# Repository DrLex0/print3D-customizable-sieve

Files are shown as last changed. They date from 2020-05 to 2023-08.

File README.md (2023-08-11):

# Customizable sieve / filter / strainer
*3D printable parametric sieve / filter / strainer (formerly thing:2578935)*

### License
[Creative Commons - Attribution](https://creativecommons.org/licenses/by/4.0/)

### Attribution
Based on Sieve (or ‘Seive’) by pcstru ([Thingiverse thing:341357](https://www.thingiverse.com/thing:341357)).

### Gallery

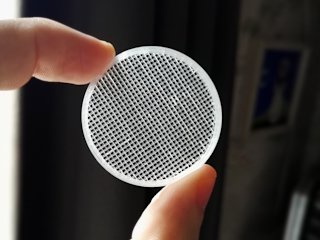
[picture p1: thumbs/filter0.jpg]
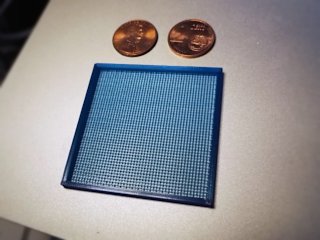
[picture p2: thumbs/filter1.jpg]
Comparison
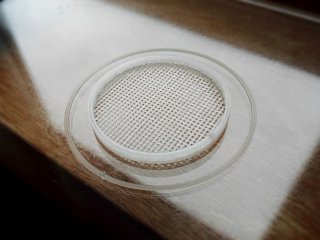
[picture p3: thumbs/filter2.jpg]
[🔎](images/filter0.jpg) [🔎](images/filter1.jpg) [🔎](images/filter2.jpg)

## Description and Instructions

This is an enhanced and customizable version of the [sieve by pcstru](https://www.thingiverse.com/thing:341357). It allows to make sieves, filters, strainers, or whatever you like to call them, in various shapes and dimensions.

Open the `.scad` file in [OpenSCAD](https://www.openscad.org/) and **[use the OpenSCAD Customizer](https://www.dr-lex.be/3d-printing/customizer.html)** to create a model with your own desired specifications.

Compared to pcstru's original, this updated version has these extra features:
* choose between round, square, or heart shapes;
* option to make any regular polygon shape by reducing the number of circle segments. The polygon will fit inside a circle of the specified outer diameter (this means making a 4-sided polygon is not the same as selecting the ‘square’ shape);
* ability to make a rectangular or elliptical shape with the `stretch` value to extend the shape in one direction (not applicable to heart shape);
* optionally add a taper to create funnel-like filters (not applicable to heart shape);
* there is a bit of extra overlap between the walls and grid, such that the grid should be well-attached to the rim even when using few or thin strands;
* the grid is perfectly centered at all times, courtesy of my unstoppable urge for detail. (But, the origin can be adjusted if desired.)

You can opt to print the grid as one set of layers, i.e. a plane with holes in it, or to print two sets of strands on top of each other (‘offset’ option). The latter is easier and probably faster to print, and may yield a more accurate filter if hole size is important. The disadvantage is that dirt tends to stick to the filter more easily.

You can also opt to lift the grid. This allows to print accurate filters with strands merely as wide as your nozzle diameter (see photos). Set the lift distance to your *first layer height* to ensure the filter only starts being printed at the *second* layer. This avoids that the strands get squished against the bed, or printed with a wider first layer extrusion, both of which would make the hole size inaccurate. You could also use a raft to the same effect, but it might be difficult to remove the filter form the raft without damaging it.

The segments parameter also affects the heart shape, but you should use a multiple of 4 in this case to ensure a smooth and usable shape.

### Print settings

The examples in the photos were printed at 0.2 mm layers, but any layer height should work. Infill should usually be set to 100% unless you are printing a design with very wide walls or so.

Both prints shown in the photos use 0.4 mm strands (with offset), and were lifted 0.25 mm (first layer height) off the bed.

For filters with narrow strands, you should ensure the extrusion width matches the strand width.

If you are trying to print a filter with a fine mesh that is only 1 extrusion wide, and the mesh disappears entirely when slicing, ensure that slicer options similar to “detect thin walls” are enabled.

## Updates

### 2017/10/10: v2.0

First published to Thingiverse.

### 2020/02/26: v2.1

Added limits and steps to parameters, to make this more usable in the OpenSCAD customizer.
Also allowed to make the outer ring shorter than the grid, or omit it entirely (use a height of 0).

### 2020/05/15: migrated to GitHub.

### 2022/03/23: v2.2

Added ‘stretch’ parameter to allow creating elongated shapes (rectangles, ellipses). Refactored the code to be more straightforward.

### 2022/05/19: v2.3

Added ‘taper’ parameter (thanks to beettlle) to generate funnel-like shapes.

### 2023/05/21: v2.4

Added grid rotation and heart shape (thanks to rixvet).

### 2023/08/11: v2.5

Allow shifting the position of the grid; reduce rendering time of final mesh by generating less structures that will be trimmed anyhow.

## Tags
`customizable`, `filter`, `grid`, `mesh`, `openscad`, `sieve`, `strainer`

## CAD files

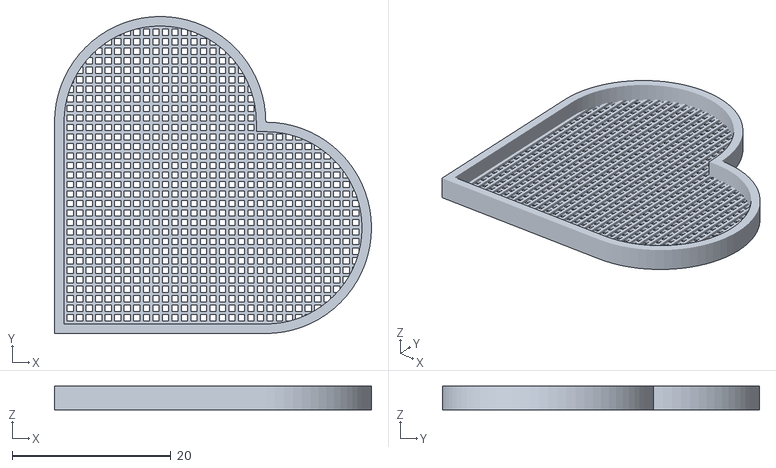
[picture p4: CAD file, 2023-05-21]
examples/sieve-heart-40mm-s_4-g_8.stl
40.0 x 40.0 x 3.00

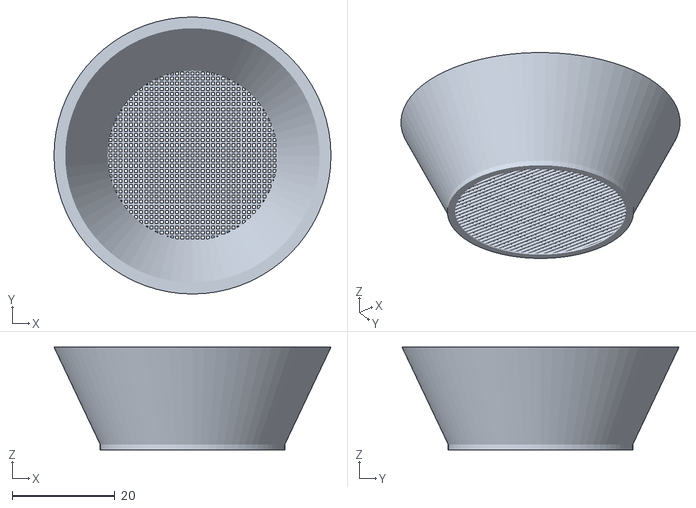
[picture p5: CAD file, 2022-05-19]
examples/sieve-funnel-36to54mm-s_4-g_6.stl
54.0 x 54.0 x 20.0

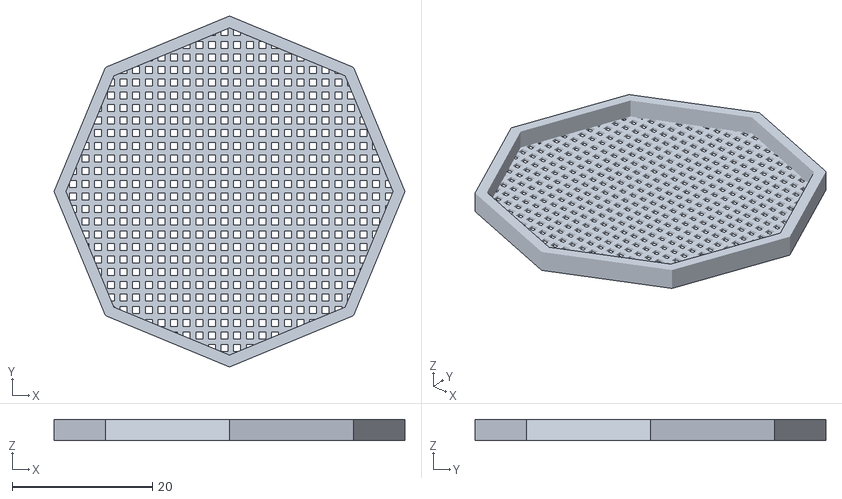
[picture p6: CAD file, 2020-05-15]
examples/sieve-poly8-50mm-s_8-g1.stl
50.0 x 50.0 x 3.00

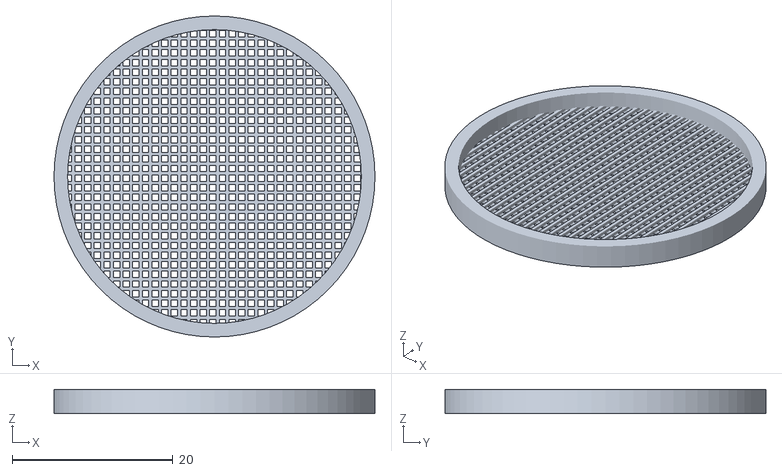
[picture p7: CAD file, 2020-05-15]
examples/sieve-round-40mm-s_4-g_8.stl
40.0 x 40.0 x 3.00

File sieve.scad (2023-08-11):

/* Customizable sieve by DrLex and contributors, formerly thing:2578935
 * based on Sieve (or Seive?) by pcstru (thing:341357).
 * Released under Creative Commons - Attribution - Share Alike license
 * https://github.com/DrLex0/print3D-customizable-sieve
 * Version 2.5, 2023/08
 */

shape = "round"; // [round,square,heart]

// All dimensions are in millimeters. For square shape, this is the length of one side. For heart shape, this is the width and depth of the heart.
outer_diameter = 40; //[5.0:.1:250.0]

// Additional X dimension length for creating elongated shapes (rectangles or ellipses). Not applicable to heart shape.
stretch = 0.0; //[0:.1:250.0]

// Width of the filter wires. You shouldn't try to go below your nozzle diameter, although it might work within certain limits.
strand_width = .4; //[.10:.01:10.00]

// Thickness (height) of the filter wires. If 'Offset strands' is enabled, the filter grid will be twice this thick.
strand_thickness = .4; //[.10:.01:5]

// Spacing between filter wires, i.e. hole size.
gap_size = .8; //[.10:.01:10.00]

// Rotation (in degrees) of filter wires in relation to shape.
grid_rotation = 0; // [0:1:90]

// Thickness (width) of the outer rim (will increase with height if taper > 1).
rim_thickness = 1.7; //[.3:.01:5]

// Total height of the outer rim.
rim_height = 3; //[0:.1:50]

// Taper of the tube: scale factor of top versus bottom contour. Not applicable to heart shape.
taper = 1; //[1:0.01:3]

// If yes, the wires will be placed in different layers, which leads to a quicker and possibly better print, especially when using thin strands.
offset_strands = "yes"; // [yes,no]

// For most accurate results with thin strands, set this to your first layer height. This will ensure the strands only start printing from the second layer, avoiding any problems due to the first layer being squished, or using a wider extrusion, etc.
lift_strands = 0; //[0.00:.01:2.00]

// Shift origin of the grid, percentage of grid pattern size (100% shift is same as 0% shift)
shift_x = 0; //[0:1:99]
shift_y = 0; //[0:1:99]

// Number of segments for round shape, low values can be used to obtain polygons that fit inside a circle of the specified outer diameter. For instance, 3 yields a triangle. Also affects heart shape.
$fn = 72; //[3:1:256]


/* [Hidden] */
shift_x_abs = (gap_size + strand_width) * shift_x / 100;
shift_y_abs = (gap_size + strand_width) * shift_y / 100;


module flat_heart(r_x, r_y, thick, inside) {
    // radius + 2 * square
    s_x = (r_x * 2) / 1.5;
    b = s_x / 2;
    w = thick * 2;

    if (inside == 1) {
    translate([-r_x, -r_x ,0])
    union() {
            square(s_x);
            translate([b, s_x, 0]) circle(d=s_x);
            translate([s_x, b, 0]) circle(d=s_x);
        }
    } else {
        translate([-r_x, -r_x ,0])
        difference() {
            union() {
                square(s_x);
                translate([b, s_x, 0]) circle(d=s_x);
                translate([s_x, b, 0]) circle(d=s_x);

            }
            translate([w/2, w/2]) square([s_x-(w/2), s_x-w]);
            translate([w/2, w/2]) square([s_x-w, s_x-(w/2)]);
            translate([b, s_x, 0]) circle(d=s_x-w);
            translate([s_x, b, 0]) circle(d=s_x-w);
       }
    }
}

// A tube:
// - hollow if inside == 0,
// - the inside volume if inside == 1,
// - else the outside volume.
// Taper applies to the entire shape, so wall thickness will vary if taper != 1.
module tube(r_x, r_y, thick, height, taper, inside=0) {
    if(shape == "round") {
        stretchx = r_x / r_y;
        linear_extrude(height=height, convexity=4, scale=taper) {
            if(inside == 0) {
                difference() {
                    scale(1/stretchx) scale([stretchx,1]) circle(r=r_x);
                    offset(delta=-thick) scale(1/stretchx) scale([stretchx,1]) circle(r=r_x);
                }
            }
            else if(inside == 1) {
                scale(1/stretchx) offset(delta=-thick) scale([stretchx,1]) circle(r=r_x);
            }
            else {
                scale(1/stretchx) scale([stretchx,1]) circle(r=r_x);
            }
        }
    }
    else if(shape == "heart") {
        linear_extrude(height = height)
            flat_heart(r_x, r_y, thick, inside);
    }
    else {
        linear_extrude(height=height, convexity=4, scale=taper) {
            if(inside == 0) {
                difference() {
                    square([2*r_x,2*r_y], center=true);
                    square([2*(r_x-thick),2*(r_y-thick)], center=true);
                }
            }
            else if(inside == 1) {
                square([2*(r_x-thick),2*(r_y-thick)], center=true);
            }
            else {
                square([2*r_x,2*r_y], center=true);
            }
        }
    }
}

// Grid
module grid(width, length, strand_width, strand_thick, gap, do_offset, sh_x, sh_y) {
    wh = width / 2;
    lh = length / 2;
    // Let's enforce symmetry just for the heck of it
    wh_align = (strand_width + gap) * floor(wh/(strand_width + gap)) + strand_width + gap/2;
    lh_align = (strand_width + gap) * floor(lh/(strand_width + gap)) + strand_width + gap/2;

    for(iy = [-wh_align:strand_width+gap:wh_align]) {
        translate([-lh,iy+sh_y,0]) cube([length,strand_width,strand_thick]) ;
    }

    for(ix = [-lh_align:strand_width+gap:lh_align]) {
        if (do_offset=="yes") {
            translate([ix+sh_x,-wh,strand_thick]) cube([strand_width,width,strand_thick]) ;
        }
        else {
            translate([ix+sh_x,-wh,0]) cube([strand_width,width,strand_thick]) ;
        }
    }
}

// Module  : Sieve
// Params :
// 	od_x = outer X dimension of the cylinder or rectangle
// 	od_y = outer Y dimension of the cylinder or rectangle
// 	strand_width = width of grid strands
// 	strand_thick = thickness of grid strands
// 	gap = gap between strands
// 	rim_thick = thickness of outer rim
// 	rim_height = height of outer rim
// 	do_offset = offset the strands ("yes" or "no")
// 	sh_x and sh_y = shift the grid over these distances
//
//
module sieve(od_x, od_y, strand_width, strand_thick, gap, rim_thick, rim_height, taper, do_offset, sh_x, sh_y) {
    or_x = od_x/2;
    or_y = od_y/2;
    upper_height = (do_offset == "yes") ?
        rim_height-2*strand_thick-lift_strands+.01 :
        rim_height-strand_thick-lift_strands+.01;
    upper_start = (do_offset == "yes") ?
        2*strand_thick-.01 :
        strand_thick-.01;

    // Add .01 margin to ensure good overlap, avoid non-manifold
    if(lift_strands > 0) {
        tube(or_x, or_y, rim_thick, lift_strands+.01, 1);
    }
    translate([0, 0, lift_strands]) {
        // Generate larger grid and then trim it to the outer shape, minus some margin.
        // However, don't make it way larger because this will needlessly increase computing time.
        intersection() {
            rotate([0, 0, grid_rotation]) grid(od_y * 1.2, od_x * 1.2, strand_width, strand_thick, gap, do_offset, sh_x, sh_y);
            translate([0,0,-.01]) tube(or_x, or_y, .1, rim_height + 2*strand_thick + .1, 1, 1);
        }
        
        translate([0, 0, upper_start]) tube(or_x, or_y, rim_thick, upper_height, taper);
    }

    tube(or_x, or_y, rim_thick-.4, rim_height - upper_height, 1);
}

sieve(outer_diameter+stretch,
      outer_diameter,
      strand_width, strand_thickness,
      gap_size,
      rim_thickness, rim_height,
      taper,
      offset_strands,
      shift_x_abs, shift_y_abs);

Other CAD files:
examples/sieve-round-40mm-s_4-g_8-old.stl

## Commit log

2020-05-15 Thingiverse exodus model 9: migrate to GitHub
    [sieve-poly8-50mm-s_8-g1.stl, sieve-round-40mm-s_4-g_8-old.stl, sieve-round-40mm-s_4-g_8.stl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]
2022-03-23 Drop version number from file name.
    We're using a VCS now.
    [sieve.scad]
2022-03-23 Added ‘stretch’ parameter to allow creating elongated shapes (rectangles, ellipses).
    Refactored the code to be more straightforward.
    [sieve.scad]
2022-05-17 Update sieve.scad
    Adding the ability to create tapers on the tubes. This is to make it easier to make sieve funnels for ground coffee.
    [sieve.scad]
2022-05-19 Setting sane value for taper
    [sieve.scad]
2022-05-19 Refine the taper feature.
    It now also works for the square shape.
    Unfortunately it is far from trivial to maintain a constant wall width when using taper. It is doable for pure circles and squares, but would be much harder in combination with the stretch feature.
    [sieve.scad]
2022-05-19 Add funnel example STL
    [sieve-funnel-36to54mm-s_4-g_6.stl]
2023-05-11 Add heart shape to supported shapes
    [sieve.scad]
2023-05-11 Add rotation to grid in relation to shape
    Usefull in combination where you like to be able to 'style' the grid.
    [sieve.scad]
2023-05-21 Update instructions for heart shape; fix incorrect heart rim width; add example.
    [sieve-heart-40mm-s_4-g_8.stl, sieve.scad]
2023-08-11 Allow moving grid origin; improve efficiency
    [sieve.scad]
